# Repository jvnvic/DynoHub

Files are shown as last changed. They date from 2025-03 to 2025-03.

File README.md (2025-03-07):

# DynoHub - Automotive Development Platform

DynoHub Logo
DynoHub Render Banner

DynoHub is an ESP32-based development board in an Arduino Uno form factor, designed for automotive applications. It was developed at the Elektroniklabor F107 for the Fachhochschule Dortmund.

## Features

- **ESP32 WROOM** – Integrated WiFi and Bluetooth
- **Modular Automotive-grade power supply** – Wide input voltage range: 4.75V to 45V
- **CAN Bus** – Automotive communication support
- **100Mbit Ethernet** – High-speed wired networking
- **MicroSD Card Slot** – Expandable storage
- **Arduino Shield Compatibility** – Supports most Arduino shields
- **Stackable Design** – Multiple boards can be stacked and bridged with a single power and CAN input

## Getting Started

DynoHub is beginner-friendly and easy to set up. An **Arduino IDE Board Configuration** is available, along with dedicated **libraries** for each peripheral, complete with example sketches.

### Installing the DynoHub Board Package in Arduino IDE

To use the DynoHub board with Arduino IDE, you need to install the custom board package. Follow these steps:

1. Open **Arduino IDE**.
2. Go to **File** > **Preferences** (Windows) or **Arduino** > **Preferences** (Mac).
3. In the **Additional Board Manager URLs** field, add the following URL:

```text
https://raw.githubusercontent.com/jvnvic/DynoHub/refs/heads/main/Software/arduino-esp32-dynohub/hardware/FH%20Dortmund/package_dynohub_index.json
```

  If there are existing URLs, separate them with a comma.

5. Click **OK** to save the settings.
6. Open **Tools** > **Board** > **Boards Manager**.
7. Search for **DynoHub** and install the corresponding board package.
8. Once installed, select the appropriate **DynoHub** board from **Tools** > **Board**.

You are now ready to program your DynoHub board with Arduino IDE!

### Libraries & Examples
Libraries are available for:
- Ethernet: https://github.com/jvnvic/UDPSender
- SD Card: https://github.com/jvnvic/EasySDMMC

Each library comes with sample code to help you get started quickly.

## Diagrams

- **Pinout Diagram**  
  Pinout

- **Functional Schematic Block Diagram**  
  Block Diagram
## License
This project is open-source and available for personal and educational use.

---

Developed at **Elektroniklabor F107** – **Fachhochschule Dortmund**

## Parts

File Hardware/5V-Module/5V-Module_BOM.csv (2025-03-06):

Comment | Designator | Footprint | LCSC Part #
1nF | C16 | C0603 | C1588
2.49k | R12 | R0603 | C108190
18k | R9 | R0603 | C25810
22k | R7 | R0603 | C31850
22nF | C12 | C0603 | C21122
50V 100uF | C3 C14 | CAPAE830X1050N | C2983307
100pF | C11 | C0603 | C14858
220nF | C2 C13 C15 | C0603 | C21120
S1M-E3_5AT | D3 | DIOM5127X229N | C968552
SRR1260-101M | L3 L4 | SRR1260101M | C5127262
SSB44-E3_5BT | D4 | DIOM5436X244N | C151740

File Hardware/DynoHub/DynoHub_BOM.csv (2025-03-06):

Comment | Designator | Footprint | LCSC Part #
1M | R1 | R0603 | C22935
1nF | C21 C43 | C0402 | C1523
1uF | C1 C4 | C0603 | C15849
2.2k | R28 R32 R50 R51 R52 | R0402 | C25879
2.2k | R54 | R0603 | C4190
2k 5% | R13 | R0402 | C4109
4.7nF 100V | C107 | C0603 | C12164
4.7uF | C19 | C0603 | C19666
5K1 | R2 | R0603 | C23186
10k | R5 R8 | R0603 | C25804
10k | R30 | R0402 | C25744
10k | R31 R35 | R0603 | C25804
10k | R55 | R0402 | C25744
10k 5% | R14 R15 R16 | R0402 | C25744
15 | R12 | R0603 | C22810
22.1k 5% | R10 | R0402 | C43473
22uF | C23 C24 | C0603 | C59461
47.5k 5% | R6 | R0402 | C25896
47K | R104 | R0603 | C25819
49 9 1% | R24 | R0402 | C25120
49 9 1% | R25 | R0402 | C25120
49 9 1% | R26 | R0402 | C25120
49 9 1% | R27 | R0402 | C25120
59 | R107 R108 | R0603 | C23086
100 | R11 | R0603 | C22775
100 nF | C103 | C0402 | C1525
100nF | C20 C29 | C0402 | C1525
100nF | C31 | C0603 | C14663
100nF | C33 C34 | C0402 | C1525
100pF 50V | C108 C109 | C0603 | C14858
220 | R17 | R0402 | C25091
470 | R9 | R0603 | C23179
600R 2A | L5 | L2012C | C3716677
BAT54C | D6 | SOT95P240X120-3N | C916424
BZX384C5V1-HE3-08 | Z1 | SOD2713X115N | C232203
C965807 | 3.3V 5V 12V | CHIPLED_0603 | C965807
CP2102N-A02-GQFN28R | IC10 | QFN50P500X500X80-29N | C964632
ESDS314DBVR | D7 | SOT95P280X145-5N | C1847859
ESP32-WROOM-32E-N8R2 | IC9 | ESP32WROOM32EN8R2 | C5361945
EVP-AF5B70 | S3 | EVPAF5B70 | C79148
FDN340P | Q3 | SOT95P237X112-3N | C75469
GG0402052R542P | D8 D9 | DIONC1006X55N | C1973257
LAN8710A-EZC | U2 | QFN50P500X500X100-33N | C46185
LMV321AIDBVR | IC1 | SOT95P280X145-5N | C484730
NUP2105LT1G | D101 | SOT96P237X111-3N | C2890118
SN65HVD230 | U3 | SOIC127P599X175-8N | C12084
SS8050-G | Q1 Q2 | SOT95P240X115-3N | C164886
TLV1117LV33DCYR | IC4 | SOT230P700X180-4N | C15578
TS3L501ERUAR | IC11 | QFN50P350X900X80-43N | C2652454
TXB0108DQSR | IC2 IC6 IC7 | TXB0108DQSR | C427057
TYPE-C-31-M-12 | J4 | HRO_TYPE-C-31-M-12 | C165948
USBLC6-2SC6 | IC3 | SOT95P280X145-6N | C7519
2.2k | R4 R18 R19 R20 R49 | R0402 | C25879
2.2k | R53 | R0603 | C4190
2.2k | R57 R58 | R0402 | C25879
2.2uF | C8 | C0402 | C12530
4.7uF | C3 | C0402 | C23733
5K1 | R3 | R0603 | C23186
10 | R21 | R0402 | C25077
10K | R111 | R0402 | C25744
10k | R23 | R0402 | C25744
10k | R29 | R0603 | C25804
12k 1% | R56 | R0402 | C25752
47uF | C5 | C0805 | C16780
100 nF | C10 | C0402 | C1525
100nF | C2 C6 C7 C9 C22 | C0402 | C1525
100nF | C27 C28 | C0603 | C14663
100nF | C30 | C0402 | C1525
100nF | C32 | C0603 | C14663
100nF | C35 | C0402 | C1525
220 | R22 | R0402 | C25091
600R 2A | L1 | L2012C | C3716677
MF-FSML050_8-2 | F1 | FUSC1608X70N | C2844464
TF-01A | MICRO_SD1 | TF-01A | C91145
HR911105A | LAN | HR911105A | C12074

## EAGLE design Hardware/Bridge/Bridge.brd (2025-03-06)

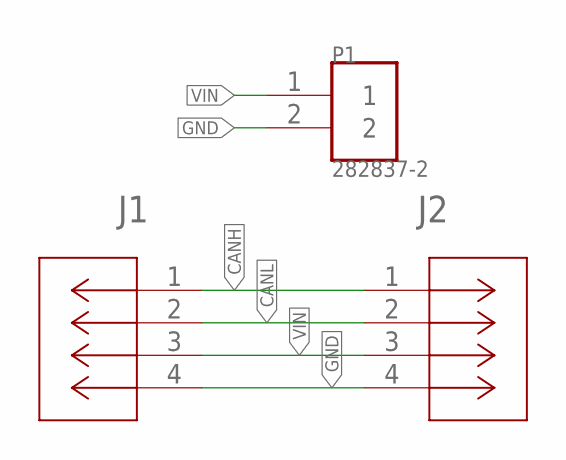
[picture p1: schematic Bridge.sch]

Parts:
J1, J2: 22027043CONN4X1_22027043_MOL; CONN4X1_22027043_MOL
P1: 282837-2; TE_282837-2

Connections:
CANH: J1.1, J2.1
CANL: J1.2, J2.2
GND: J1.4, J2.4, P1.2
VIN: J1.3, J2.3, P1.1

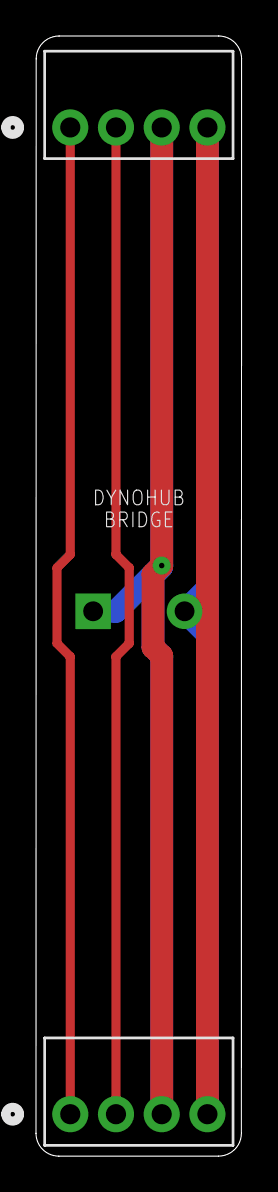
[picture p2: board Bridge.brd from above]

Board: 2 copper layers, 11.4 x 62.2 mm, 3 parts (1 on the bottom side), 4 nets.

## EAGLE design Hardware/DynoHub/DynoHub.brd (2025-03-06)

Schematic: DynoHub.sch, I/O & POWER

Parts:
3.3V, 5V, 12V: C965807; CHIPLED_0603
C1, C4: 1uF; C0603
C2, C6, C7, C9, C20, C22, C29, C30, C33, C34, C35: 100nF; C0402K
C3: 4.7uF; C0402K
C5: 47uF; C0805
C8: 2.2uF; C0402K
C10, C103: 100 nF; C0402K
C19: 4.7uF; C0603
C21, C43: 1nF; C0402K
C23, C24: 22uF; C0603
C27, C28, C31, C32: 100nF; C0603
C107: 4.7nF 100V; C0603
C108, C109: 100pF 50V; C0603
CAN_TX: SJ
D6: BAT54C; SOT95P240X120-3N
D7: ESDS314DBVR; SOT95P280X145-5N
D8, D9: GG0402052R542P; DIONC1006X55N
D101: NUP2105LT1G; SOT96P237X111-3N
ETH_EN: SJ
F1: MF-FSML050_8-2; FUSC1608X70N
IC1: LMV321AIDBVR; SOT95P280X145-5N
IC2, IC6, IC7: TXB0108DQSR
IC3: USBLC6-2SC6; SOT95P280X145-6N
IC4: TLV1117LV33DCYR; SOT230P700X180-4N
IC9: ESP32-WROOM-32E-N8R2; ESP32WROOM32EN8R2
IC10: CP2102N-A02-GQFN28R; QFN50P500X500X80-29N
IC11: TS3L501ERUAR; QFN50P350X900X80-43N
J4: TYPE-C-31-M-12; HRO_TYPE-C-31-M-12
J5, J6: 1718570004CONN_SD-171857-0001_M265_04_MO; CONN_SD-171857-0001_M265_04_MO
J9: HR911105A; HANRUN_HR911105A
J-SD_DAT: SJ
JANALOG1: 6x1F-H8.5-L14.5mm; 1X06
JHIGH1: 10x1F-H8.5-L14.5mm; 1X10
JLOW1: 8x1F-H8.5-L14.5mm; 1X08
J_SD_CLK: SJ
J_SD_CMD: SJ
L1, L5: 600R 2A; L2012C
MICRO_SD1: TF-01A
POWER1: 8x1F-H8.5-L14.5mm; 1X08
Q1, Q2: SS8050-G; SOT95P240X115-3N
Q3: FDN340P; SOT95P237X112-3N
R1: 1M; R0603
R2, R3: 5K1; R0603
R4, R18, R19, R20, R28, R32, R49, R50, R51, R52, R57, R58: 2.2k; R0402
R5, R8, R29, R31, R35: 10k; R0603
R6: 47.5k 5%; R0402
R9: 470; R0603
R10: 22.1k 5%; R0402
R11: 100; R0603
R12: 15; R0603
R13: 2k 5%; R0402
R14, R15, R16: 10k 5%; R0402
R17, R22: 220; R0402
R21: 10; R0402
R23, R30, R55: 10k; R0402
R24, R25, R26, R27: 49,9 1%; R0402
R53, R54: 2.2k; R0603
R56: 12k 1%; R0402
R104: 47K; R0603
R107, R108: 59; R0603
R111: 10K; R0402
S3: EVP-AF5B70; EVPAF5B70
SJ1: SJ
U2: LAN8710A-EZC; QFN50P500X500X100-33N
U3: SN65HVD230; SOIC127P599X175-8N
U$1, U$2, U$3, U$4, U$5, U$6, U$7, U$13, U$14, U$15, U$16, U$17, U$18, U$19, U$20, U$21, U$22, U$23, U$24, U$25, U$26, U$27, U$28, U$29, U$30, U$31, U$32, U$33, U$34, U$35: NC
U$8, U$9, U$10, U$11, U$12: 2X3MM_PAD
Z1: BZX384C5V1-HE3-08; SOD2713X115N

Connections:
3V3: 3.3V.A, C2.1, C3.1, C4.1, C19.1, C20.1, C22.1, C23.1, C27.2, C29.2, C31.2, C35.2, C103.1, ETH_EN.1, IC1.4 (-IN), IC2.5 (VCCA), IC4.2 (OUTPUT_1), IC4.4 (OUTPUT_2), IC6.5 (VCCA), IC7.5 (VCCA), IC9.2 (3V3), IC10.6 (VDD), IC10.7 (VREGIN), IC11.39 (VDD_7), J9.9 (GA), L1.1, L5.1, POWER1.4, R4.2, R13.1, R18.2, R19.2, R20.2, R23.2, R28.2, R51.2, R52.2, R53.2, R54.2, R55.2, R111.2, U2.12 (VDDIO), U3.3 (VCC)
5V: 5V.A, C1.1, C28.2, C30.2, C32.2, IC1.5 (V+), IC2.16 (VCCB), IC4.3 (INPUT), IC6.16 (VCCB), IC7.16 (VCCB), POWER1.2, POWER1.5, Q3.2 (S), U$8.P$1
12V: 12V.A, POWER1.8, R8.2, U$9.P$1
!ETH_EN: ETH_EN.2, IC11.13 (SEL), R35.2
A0/ADC1_6/GPIO34: IC7.10 (A8), IC9.6 (IO34)
A0/ADC1_6/GPIO34_5V: IC7.11 (B8), JANALOG1.1
A1/ADC1_7/GPIO35: IC7.9 (A7), IC9.7 (IO35)
A1/ADC1_7/GPIO35_5V: IC7.12 (B7), JANALOG1.2
A2/ADC1_4/GPIO32: IC7.8 (A6), IC9.8 (IO32)
A2/ADC1_4/GPIO32_5V: IC7.13 (B6), JANALOG1.3
A3/ADC1_5/GPIO33: IC7.7 (A5), IC9.9 (IO33)
A3/ADC1_5/GPIO33_5V: IC7.14 (B5), JANALOG1.4
A4/TXCAN/ADC2_0/GPIO4: CAN_TX.1, IC7.4 (A4), IC9.26 (IO4)
A4/TXCAN/ADC2_0/GPIO4_5V: IC7.17 (B4), JANALOG1.5
A5/ADC2_2/SD_DAT0/GPIO2: D6.1 (A1), IC7.3 (A3), IC9.24 (IO2), J-SD_DAT.1
A5/ADC2_2/SD_DATO/GPIO2_5V: IC7.18 (B3), JANALOG1.6
AREF/GPI39: IC9.5 (SENSOR_VN), JHIGH1.8
CANGND_BF_C: C107.2, SJ1.1
CANH_P: C109.2, D101.2 (A_2), J5.4, J6.4, R108.1, U3.7 (CANH)
CANL_BF_JMP: R107.1, R108.2, SJ1.2
CANL_N: C108.2, D101.1 (A_1), J5.3, J6.3, R107.2, U3.6 (CANL)
CC1: J4.A5 (CC1), R3.2
CC2: J4.B5 (CC2), R2.2
CLK: MICRO_SD1.5 (CLK), R22.1
CMP: IC1.3 (+IN), R5.2, R8.1, Z1.1 (K)
CS/D10/GPIO5: IC6.8 (A6), IC9.29 (IO5)
CS/D10/GPIO5_5V: IC6.13 (B6), JHIGH1.3
D0/UART_RXD: IC2.10 (A8), IC9.34 (RXD0), IC10.25 (RXD)
D0/UART_RXD_5V: IC2.11 (B8), JLOW1.1
D1/UART_TXD: IC2.9 (A7), IC9.35 (TXD0), IC10.26 (TXD)
D1/UART_TXD_5V: IC2.12 (B7), JLOW1.2
D2/EMAC_RXD1/GPIO26: IC9.11 (IO26), IC11.3 (A1)
D2/GPIO26: IC2.8 (A6), IC11.35 (C1)
D2/GPIO26_5V: IC2.13 (B6), JLOW1.3
D3/EMAC_RXD0/GPIO25: IC9.10 (IO25), IC11.6 (A2)
D3/GPIO25: IC2.7 (A5), IC11.32 (C2)
D3/GPIO25_5V: IC2.14 (B5), JLOW1.4
D4/EMAC_CO180/GPIO17: IC9.28 (IO17), IC11.2 (A0)
D4/GPIO17: IC2.4 (A4), IC11.36 (C0)
D4/GPIO17_5V: IC2.17 (B4), JLOW1.5
D5/GPIO16: IC2.3 (A3), IC9.27 (IO16)
D5/GPIO16_5V: IC2.18 (B3), JLOW1.6
D6/EMAC_RX_CRS_DV/GPIO27: IC9.12 (IO27), IC11.7 (A3)
D6/GPIO27: IC2.2 (A2), IC11.31 (C3)
D6/GPIO27_5V: IC2.19 (B2), JLOW1.7
D7/SD_CLK/GPIO14: IC2.1 (A1), IC9.13 (IO14), J_SD_CLK.1
D7/SD_CLK/GPIO14_5V: IC2.20 (B1), JLOW1.8
D8/GPIO12: IC6.10 (A8), IC9.14 (IO12)
D8/GPIO12_5V: IC6.11 (B8), JHIGH1.1
D9/GPIO13: IC6.9 (A7), IC9.16 (IO13)
D9/GPIO13_5V: IC6.12 (B7), JHIGH1.2
DAT0: MICRO_SD1.7 (DAT0), R21.1
DAT1: MICRO_SD1.8 (DAT1), R4.1
DAT2: MICRO_SD1.1 (DAT2), R20.1
DAT3: MICRO_SD1.2 (CD/DAT3), R19.1
EMAC_CO180: IC11.38 (B0), U2.5 (XTAL1/CLKIN)
EMAC_MDC: IC11.28 (B5), U2.17 (MDC)
EMAC_MDIO: IC11.29 (B4), R53.1, U2.16 (MDIO)
EMAC_RXD0: IC11.34 (B2), R51.1, U2.11 (RXD0/MODE0)
EMAC_RXD1: IC11.37 (B1), R52.1, U2.10 (RXD1/MODE1)
EMAC_RX_CRS_DV: IC11.33 (B3), R54.1, U2.15 (COL/CRS_DV/MODE2)
EMAC_TXD0: IC11.24 (B7), U2.22 (TXD0)
EMAC_TXD1: IC11.17 (LED__B0), U2.23 (TXD1)
EMAC_TX_EN: IC11.25 (B6), U2.21 (TXEN)
ESP_EN: C6.1, C10.1, IC9.3 (EN), POWER1.3, Q1.3 (C), R111.1, S3.A1 (NO_1), S3.A2 (NO_2)
ETH_LED_G: J9.10 (GC), R57.2
ETH_LED_Y: J9.12 (YA), R58.2
ETH_VDDCR: C7.1, C8.1, U2.6 (VDDCR)
GND: C1.2, C2.2, C3.2, C4.2, C5.1, C6.2, C7.2, C8.2, C9.2, C10.2, C19.2, C20.2, C21.2, C22.2, C23.2, C24.2, C27.1, C28.1, C29.1, C30.1, C31.1, C32.1, C33.2, C34.2, C35.1, C43.2, C103.2, C107.1, C108.1, C109.1, D7.2 (GND), D101.3 (A_3), IC1.2 (V-), IC2.15 (GND), IC3.2 (GND), IC4.1 (GND), IC6.15 (GND), IC7.15 (GND), IC9.1 (GND_1), IC9.15 (GND_2), IC9.38 (GND_3), IC9.39 (GND_4), IC9.40 (GND_5), IC9.41 (GND_6), IC9.42 (GND_7), IC9.43 (GND_8), IC9.44 (GND_9), IC9.45 (GND_10), IC9.46 (GND_11), IC9.47 (GND_12), IC10.3 (GND_1), IC10.29 (GND_2), IC11.5 (PD), IC11.43 (GND), J4.A1_B12 (GND), J4.B1_A12 (GND), J5.1, J6.1, J9.8 (GND), J9.11 (YC), JHIGH1.7, MICRO_SD1.6 (VSS), MICRO_SD1.MP1 (SHIELD), MICRO_SD1.MP2 (SHIELD), MICRO_SD1.MP3 (SHIELD), MICRO_SD1.MP4 (SHIELD), POWER1.6, POWER1.7, R1.1, R2.1, R3.1, R5.1, R6.1, R9.1, R11.1, R12.1, R14.1, R29.1, R30.1, R31.1, R32.2, R35.1, R49.2, R50.2, R56.1, R104.1, S3.B1 (COM_1), S3.B2 (COM_2), U2.24 (TXD2), U2.25 (TXD3), U2.33 (VSS), U3.2 (GND), U$11.P$1, U$12.P$1, Z1.2 (A)
GPIO0: D6.2 (A2), IC9.25 (IO0), Q2.3 (C), R17.2
MISO/D12/EMAC_TXD0/GPIO19: IC9.31 (IO19), IC11.12 (A7)
MISO/D12/GPIO19: IC6.4 (A4), IC11.22 (C7)
MISO/D12/GPIO19_5V: IC6.17 (B4), JHIGH1.5
MOSI/D11/EMAC_MDC/GPIO23: IC9.37 (IO23), IC11.10 (A5)
MOSI/D11/GPIO23: IC6.7 (A5), IC11.26 (C5)
MOSI/D11/GPIO23_5V: IC6.14 (B5), JHIGH1.4
unnamed: J4.S1 (SHIELD), J4.S2 (SHIELD), J4.S3 (SHIELD), J4.S4 (SHIELD), R1.2
unnamed: IC10.9 (RSTB), R13.2
unnamed: IC10.11 (SUSPENDB), R14.2
unnamed: Q1.1 (B), R16.1
unnamed: 12V.C, R9.2
unnamed: R104.2, U3.8 (RS)
unnamed: IC1.1 (OUT), Q3.1 (G)
unnamed: Q2.1 (B), R15.1
unnamed: D6.3 (CC), R17.1
unnamed: 5V.C, R11.2
unnamed: 3.3V.C, R12.2
unnamed: C21.1, J9.15 (SHIELD), J9.16 (SHIELD)
unnamed: F1.1, J4.A4_B9 (VBUS), J4.B4_A9 (VBUS)
unnamed: R28.1, U2.9 (RXD2/RMIISEL)
unnamed: R32.1, U2.8 (RXD3/PHYAD2)
unnamed: R49.1, U2.13 (RXER/RXD4/PHYAD0)
unnamed: R50.1, U2.7 (RXCLK/PHYAD1)
unnamed: C43.1, R55.1, U2.19 (NRST)
unnamed: R56.2, U2.32 (RBIAS)
unnamed: R58.1, U2.3 (LED1/REGOFF)
unnamed: R57.1, U2.2 (LED2/NINTSEL)
OE_A: IC2.6 (OE), R29.2
OE_B: IC6.6 (OE), R30.2
OE_C: IC7.6 (OE), R31.2
PC0: IC7.1 (A1)
PC0O: IC7.20 (B1)
PC1: IC7.2 (A2)
PC1O: IC7.19 (B2)
PHY_VDD: C9.1, C24.1, C33.1, C34.1, J9.4, J9.5, L5.2, R24.2, R25.2, R26.2, R27.2, U2.1 (VDD2A), U2.27 (VDD1A)
RXCAN/GPI36: IC9.4 (SENSOR_VP), U3.4 (R)
RX_N: D7.3 (I/O2), D9.1, J9.1 (TD+), R27.1, U2.30 (RXN)
RX_P: D7.1 (I/O1), D9.2, J9.3 (RD+), R25.1, U2.31 (RXP)
SCK/D13/EMAC_MDIO/GPIO18: IC9.30 (IO18), IC11.9 (A4)
SCK/D13/GPIO18: IC6.3 (A3), IC11.27 (C4)
SCK/D13/GPIO18_5V: IC6.18 (B3), JHIGH1.6
SCL/EMAC_TXD1/GPIO22: IC9.36 (IO22), IC11.15 (LED_A0)
SCL/GPIO22: IC6.1 (A1), IC11.19 (LED_C0)
SCL/GPIO22_5V: IC6.20 (B1), JHIGH1.10
SDA/EMAC_TX_EN/GPIO21: IC9.33 (IO21), IC11.11 (A6)
SDA/GPIO21: IC6.2 (A2), IC11.23 (C6)
SDA/GPIO21_5V: IC6.19 (B2), JHIGH1.9
SD_CLK/GPIO14_S: J_SD_CLK.2, R22.2
SD_CMD/GPIO15: IC9.23 (IO15), J_SD_CMD.1
SD_CMD/GPIO15_S: J_SD_CMD.2, MICRO_SD1.3 (CMD), R23.1
SD_DAT0/GPIO2_S: J-SD_DAT.2, R18.1, R21.2
TXCAN: CAN_TX.2, U3.1 (D)
TX_N: D7.4 (I/O3), D8.2, J9.2 (TD-), R26.1, U2.28 (TXN)
TX_P: D7.5 (I/O4), D8.1, J9.6 (RD-), R24.1, U2.29 (TXP)
USB_CTS: IC10.23 (CTS)
USB_DATA_CON_N: IC3.6 (I/O1_2), J4.A7 (DN1), J4.B7 (DN2)
USB_DATA_CON_P: IC3.4 (I/O2_2), J4.A6 (DP1), J4.B6 (DP2)
USB_DATA_N: IC3.1 (I/O1_1), IC10.5 (D-)
USB_DATA_P: IC3.3 (I/O2_1), IC10.4 (D+)
USB_DCD: IC10.1 (DCD)
USB_DSR: IC10.27 (DSR)
USB_DTR: IC10.28 (DTR), Q2.2 (E), R16.2
USB_RI: IC10.2 (RI_/_CLK)
USB_RTS: IC10.24 (RTS), Q1.2 (E), R15.2
VBUS: F1.2, IC3.5 (VBUS), IC10.8 (VBUS), Q3.3 (D), R6.2, R10.1, R10.2
VDD: C5.2, L1.2, MICRO_SD1.4 (VDD)
VIN: J5.2, J6.2, U$10.P$1

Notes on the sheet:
Auto program DTR RTS-->EN IO0 1 1 1 1 0 0 1 1 1 0 0 1 0 1 1 0
Pulldown OE nochmal prüfen
The PHY is set up as follows: MODE: All capable(10/100Base) -Auto-negotiation enabled -RMII Configuration -SMI address: 0x00
SEL
Function
A -> B
A -> C
Disconnect
Turn on S1 to deactivate Ethernet
limit cmp to 5.1V
7V-30V input

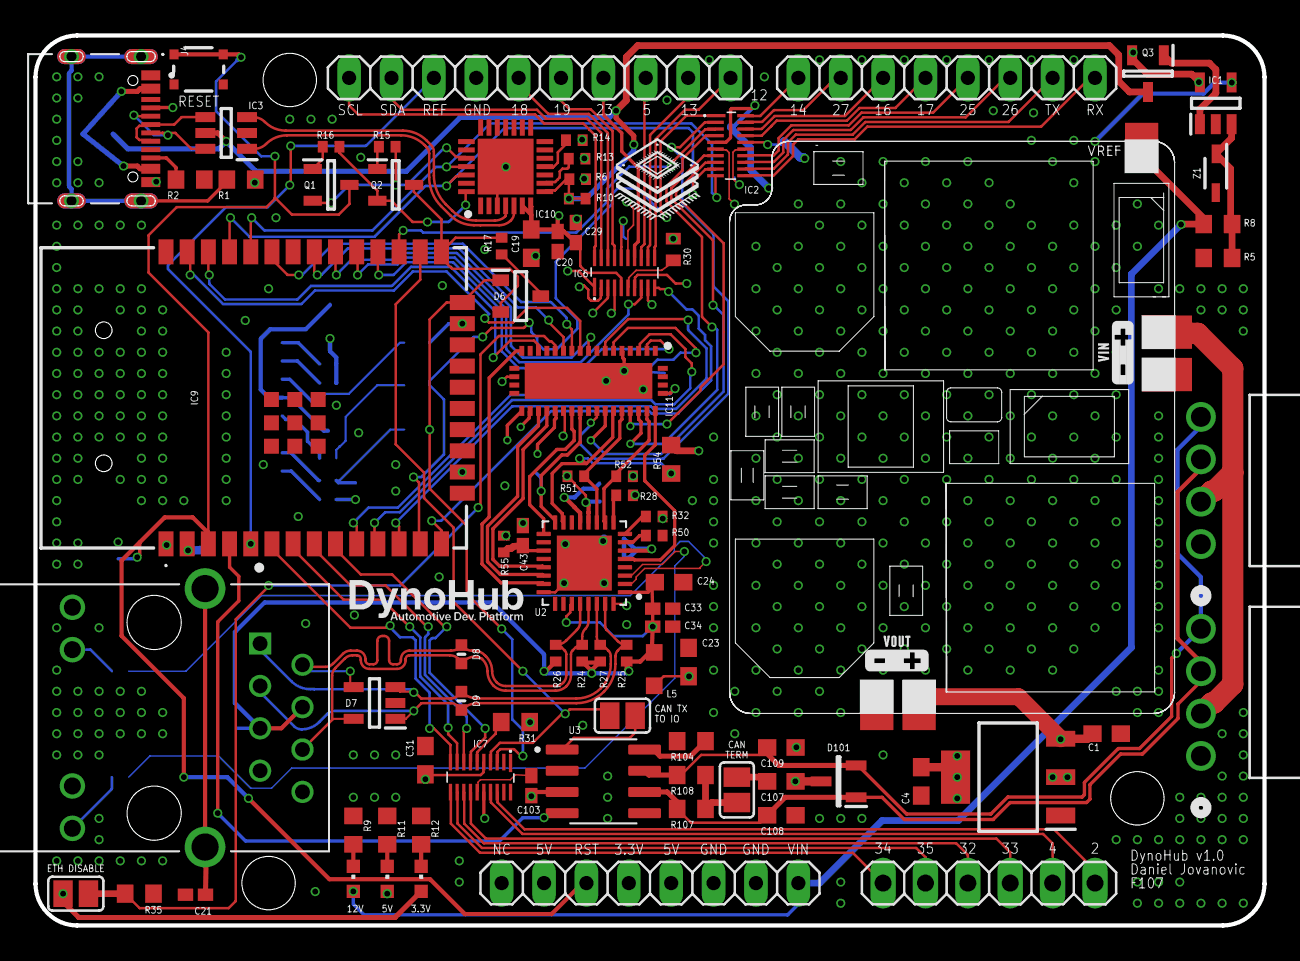
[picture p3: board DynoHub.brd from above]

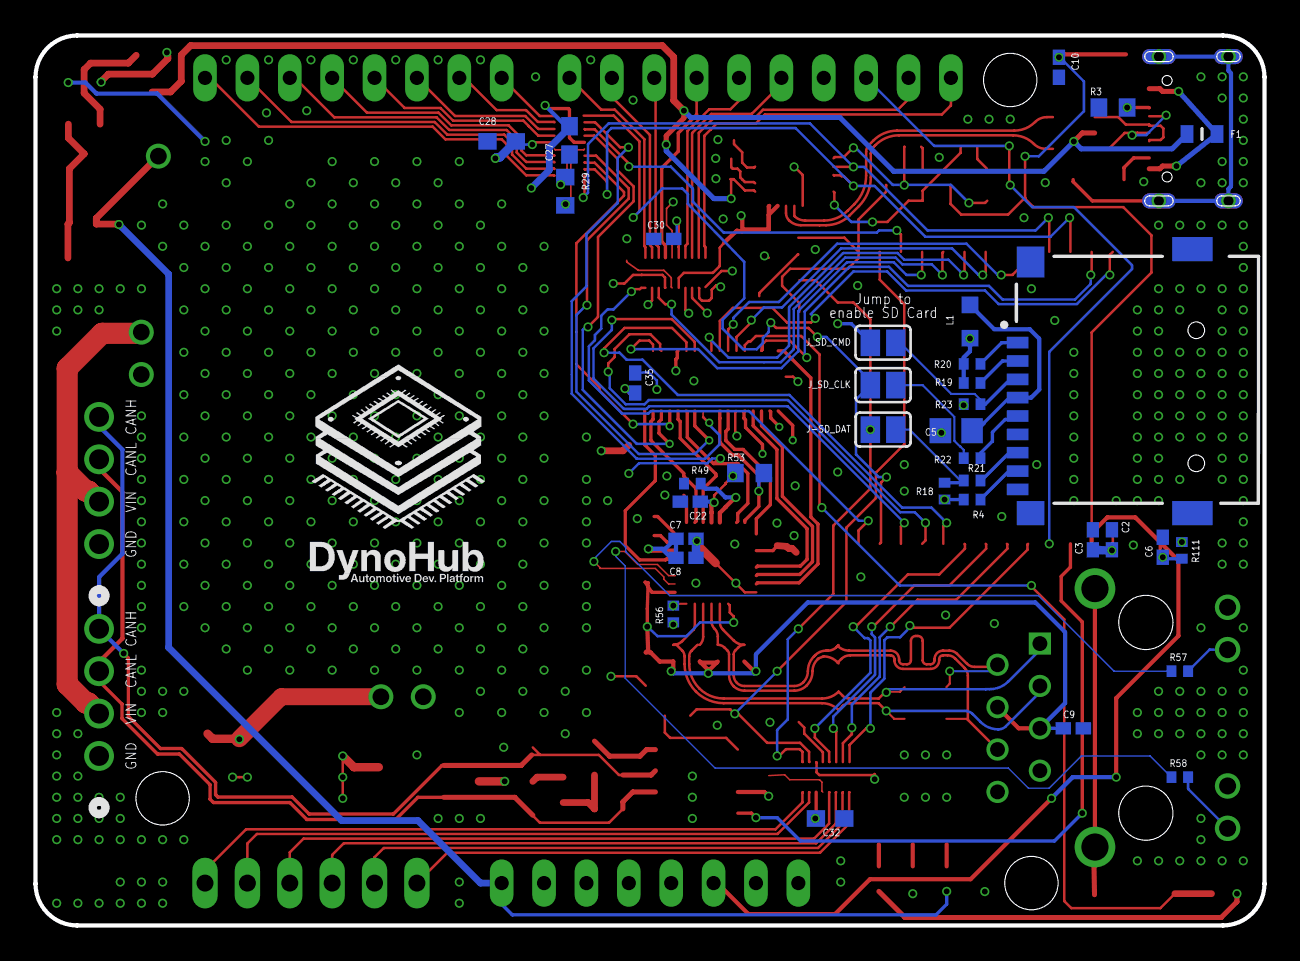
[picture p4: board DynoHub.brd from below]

Board: 4 copper layers, 73.7 x 53.3 mm, 153 parts (35 on the bottom side), 129 nets.

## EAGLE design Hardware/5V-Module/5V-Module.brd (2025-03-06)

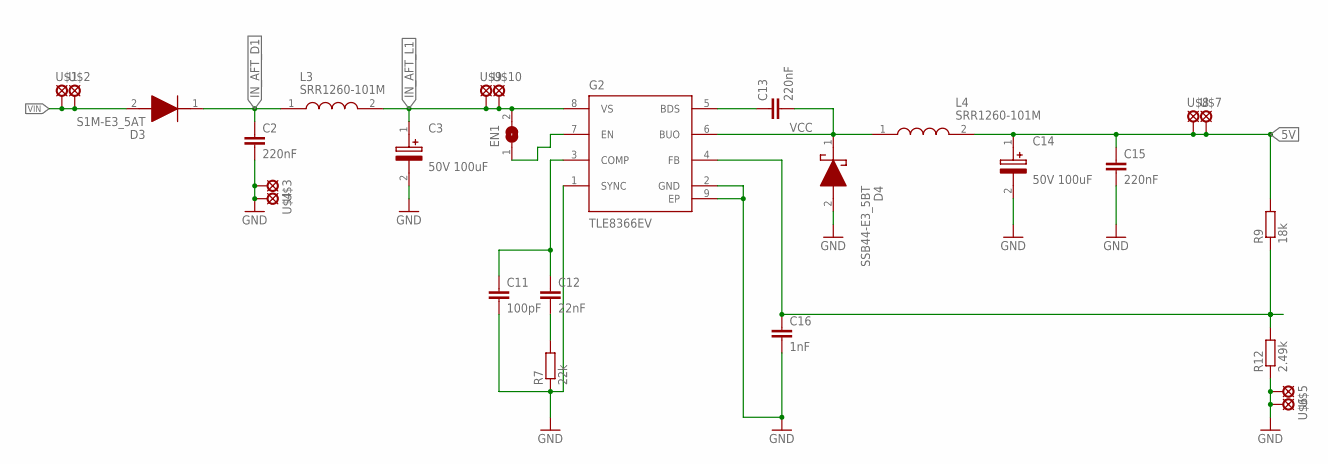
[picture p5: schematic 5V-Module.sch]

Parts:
C2, C13, C15: 220nF; C0603
C3, C14: 50V 100uF; CAPAE830X1050N
C11: 100pF; C0603
C12: 22nF; C0603
C16: 1nF; C0603
D3: S1M-E3_5AT; DIOM5127X229N
D4: SSB44-E3_5BT; DIOM5436X244N
EN1: SJ
G2: TLE8366EV; SOIC127P600X170-9N-1
L3, L4: SRR1260-101M; SRR1260101M
R7: 22k; R0603
R9: 18k; R0603
R12: 2.49k; R0603
U$1, U$2, U$3, U$4, U$5, U$6, U$7, U$8, U$9, U$10: 2MM_PAD

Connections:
5V: C14.1 (+), C15.1, L4.2, R9.2, U$7.P$1, U$8.P$1
GND: C2.2, C3.2 (-), C11.2, C14.2 (-), C15.2, C16.2, D4.2 (A), G2.1 (SYNC), G2.2 (GND), G2.9 (EP), R7.1, R12.1, U$3.P$1, U$4.P$1, U$5.P$1, U$6.P$1
IN_AFT_D1: C2.1, D3.1 (K), L3.1
IN_AFT_L1: C3.1 (+), EN1.2, G2.8 (VS), L3.2, U$9.P$1, U$10.P$1
unnamed: C11.1, C12.1, G2.3 (COMP)
unnamed: C12.2, R7.2
unnamed: C13.1, G2.5 (BDS)
unnamed: C16.1, G2.4 (FB), R9.1, R12.2
unnamed: EN1.1, G2.7 (EN)
VCC: C13.2, D4.1 (K), G2.6 (BUO), L4.1
VIN: D3.2 (A), U$1.P$1, U$2.P$1

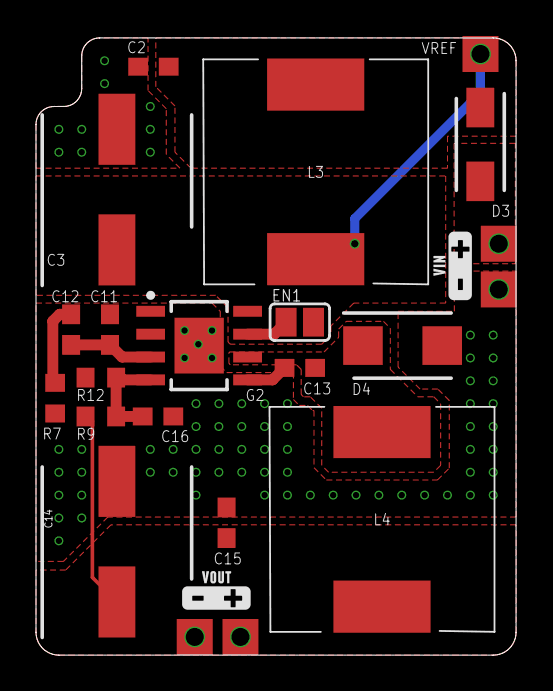
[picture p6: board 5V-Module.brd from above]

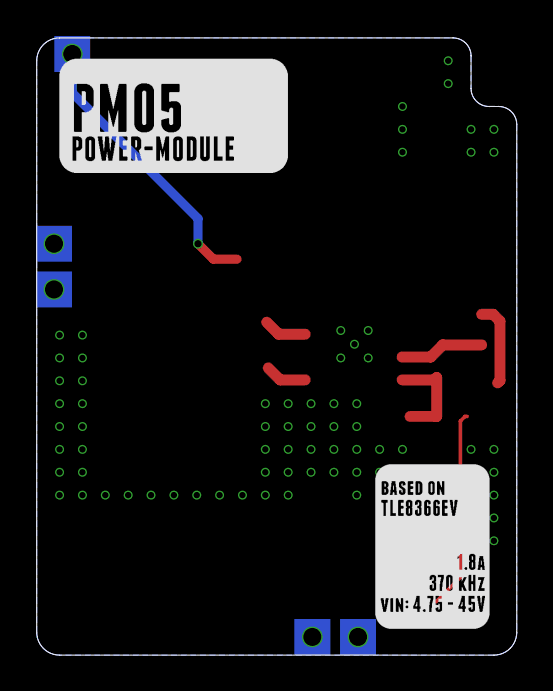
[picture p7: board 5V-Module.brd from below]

Board: 2 copper layers, 26.7 x 34.3 mm, 27 parts (5 on the bottom side), 11 nets.

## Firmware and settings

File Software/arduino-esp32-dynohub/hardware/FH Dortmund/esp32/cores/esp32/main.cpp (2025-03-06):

#include "freertos/FreeRTOS.h"
#include "freertos/task.h"
#include "esp_task_wdt.h"
#include "soc/rtc.h"
#include "Arduino.h"
#if (ARDUINO_USB_CDC_ON_BOOT | ARDUINO_USB_MSC_ON_BOOT | ARDUINO_USB_DFU_ON_BOOT) && !ARDUINO_USB_MODE
#include "USB.h"
#if ARDUINO_USB_MSC_ON_BOOT
#include "FirmwareMSC.h"
#endif
#endif

#include "chip-debug-report.h"

#ifndef ARDUINO_LOOP_STACK_SIZE
#ifndef CONFIG_ARDUINO_LOOP_STACK_SIZE
#define ARDUINO_LOOP_STACK_SIZE 8192
#else
#define ARDUINO_LOOP_STACK_SIZE CONFIG_ARDUINO_LOOP_STACK_SIZE
#endif
#endif

TaskHandle_t loopTaskHandle = NULL;

#if CONFIG_AUTOSTART_ARDUINO
#if CONFIG_FREERTOS_UNICORE
void yieldIfNecessary(void) {
  static uint64_t lastYield = 0;
  uint64_t now = millis();
  if ((now - lastYield) > 2000) {
    lastYield = now;
    vTaskDelay(5);  //delay 1 RTOS tick
  }
}
#endif

bool loopTaskWDTEnabled;

__attribute__((weak)) size_t getArduinoLoopTaskStackSize(void) {
  return ARDUINO_LOOP_STACK_SIZE;
}

__attribute__((weak)) bool shouldPrintChipDebugReport(void) {
  return false;
}

void loopTask(void *pvParameters) {
#if !defined(NO_GLOBAL_INSTANCES) && !defined(NO_GLOBAL_SERIAL)
  // sets UART0 (default console) RX/TX pins as already configured in boot or as defined in variants/pins_arduino.h
  Serial0.setPins(gpioNumberToDigitalPin(SOC_RX0), gpioNumberToDigitalPin(SOC_TX0));
#endif
#if ARDUHAL_LOG_LEVEL >= ARDUHAL_LOG_LEVEL_DEBUG
  printBeforeSetupInfo();
#else
  if (shouldPrintChipDebugReport()) {
    printBeforeSetupInfo();
  }
#endif
  setup();
#if ARDUHAL_LOG_LEVEL >= ARDUHAL_LOG_LEVEL_DEBUG
  printAfterSetupInfo();
#else
  if (shouldPrintChipDebugReport()) {
    printAfterSetupInfo();
  }
#endif
  for (;;) {
#if CONFIG_FREERTOS_UNICORE
    yieldIfNecessary();
#endif
    if (loopTaskWDTEnabled) {
      esp_task_wdt_reset();
    }
    loop();
    if (serialEventRun) {
      serialEventRun();
    }
  }
}

extern "C" void app_main() {
#ifdef F_XTAL_MHZ
#if !CONFIG_IDF_TARGET_ESP32S2  // ESP32-S2 does not support rtc_clk_xtal_freq_update
  rtc_clk_xtal_freq_update((rtc_xtal_freq_t)F_XTAL_MHZ);
  rtc_clk_cpu_freq_set_xtal();
#endif
#endif
#ifdef F_CPU
  setCpuFrequencyMhz(F_CPU / 1000000);
#endif
#if ARDUINO_USB_CDC_ON_BOOT && !ARDUINO_USB_MODE
  Serial.begin();
#endif
#if ARDUINO_USB_MSC_ON_BOOT && !ARDUINO_USB_MODE
  MSC_Update.begin();
#endif
#if ARDUINO_USB_DFU_ON_BOOT && !ARDUINO_USB_MODE
  USB.enableDFU();
#endif
#if ARDUINO_USB_ON_BOOT && !ARDUINO_USB_MODE
  USB.begin();
#endif
  loopTaskWDTEnabled = false;
  initArduino();
  xTaskCreateUniversal(loopTask, "loopTask", getArduinoLoopTaskStackSize(), NULL, 1, &loopTaskHandle, ARDUINO_RUNNING_CORE);
}

#endif

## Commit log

2025-03-06 push board package
    [app3M_fat9M_16MB.csv, app3M_fat9M_fact512k_16MB.csv, app3M_spiffs9M_fact512k_16MB.csv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]
2025-03-06 updated board package
    [app3M_fat9M_16MB.csv, app3M_fat9M_fact512k_16MB.csv, app3M_spiffs9M_fact512k_16MB.csv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]
2025-03-06 board package update
2025-03-06 updated board info
2025-03-06 updated board
2025-03-06 updated board config

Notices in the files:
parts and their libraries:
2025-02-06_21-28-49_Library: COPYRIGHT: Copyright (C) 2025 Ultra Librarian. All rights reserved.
